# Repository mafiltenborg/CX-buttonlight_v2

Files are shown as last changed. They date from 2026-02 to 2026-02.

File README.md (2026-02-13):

# CX-buttonlight_v2

Better version of the LED lightsource for buttons in your [Citroën CX](https://en.wikipedia.org/wiki/Citro%C3%ABn_CX).

Building on the learnings from [its predecessor](https://github.com/mafiltenborg/CX_buttonlight), the improved version of this little lightsource adds drop-in placement without the need for neither wiring nor the plastic housing from the existing Citroën part. This enables more light or less powerdraw as required by the user. Also, the light module becomes a whole lot easier to manufacture and put in its final position. This version, however, breaks all the originality because it is a component replacement, not a consumables replacement.

Because this device does not use the OE bulb holder (made out of yellow plastic) it allows for the use of any colour LED you fancy. The green light in the ashtray and the green light near the ignition key and the green light emanating from the dashboard computer can now be accompanied by green light from the buttons, making a unison expression. Some might want that...

Update: This device has now been superseded with  one that uses a different LED driving principle (constant current) and even lower power consumption. Go to [CX buttonlight v3](https://github.com/mafiltenborg/cx_buttonlight_v3) to learn more.

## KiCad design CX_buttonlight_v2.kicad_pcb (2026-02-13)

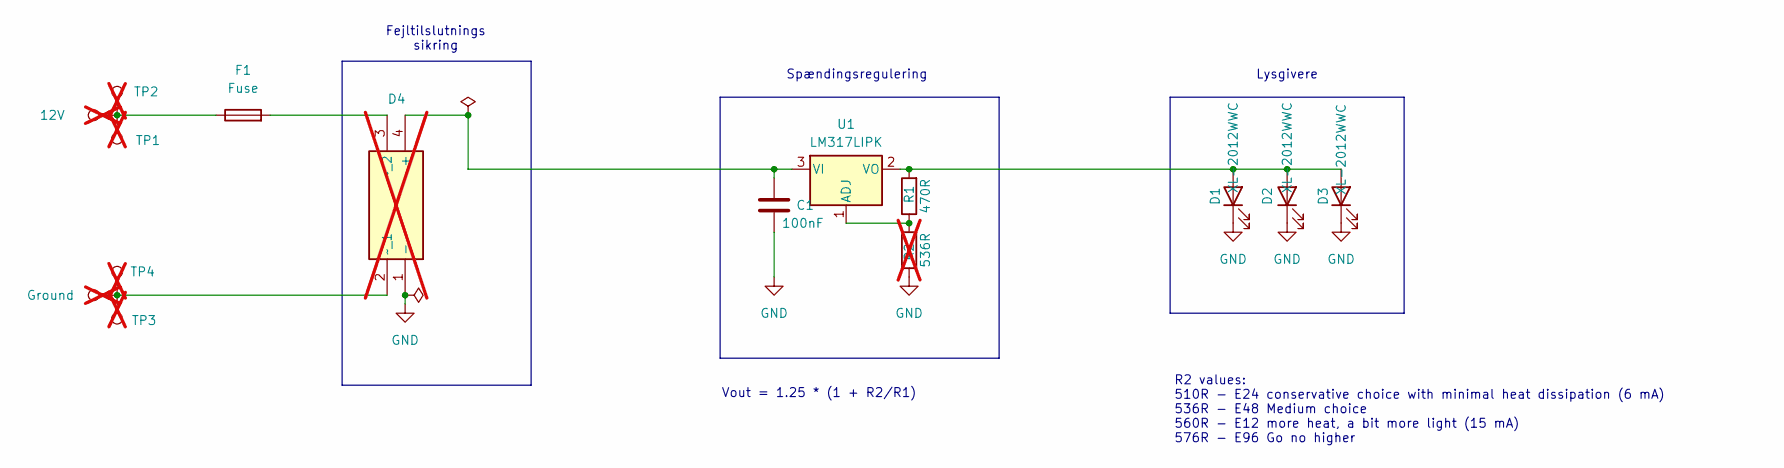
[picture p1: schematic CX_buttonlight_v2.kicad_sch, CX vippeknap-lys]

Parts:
C1: 100nF; C_0805_2012Metric_Pad1.18x1.45mm_HandSolder; LCSC Part # C49678
D1, D2, D3: XL-2012WWC; LED_0805_2012Metric_Pad1.15x1.40mm_HandSolder; LCSC Part # C965820
D4: BAS4002ARPPE6327HTSA1; Manufacturer_Part_Number BAS4002ARPPE6327HTSA1; Mouser Part Number 726-BAS4002ARPPE6; not fitted
F1: Fuse; Fuse_0805_2012Metric_Pad1.15x1.40mm_HandSolder
Ground1: Ground; TestPoint_THTPad_D1.5mm_Drill0.7mm; not fitted
R1: 470R; R_0805_2012Metric_Pad1.20x1.40mm_HandSolder; LCSC Part # C114564
R2: 536R; R_0805_2012Metric_Pad1.20x1.40mm_HandSolder; not fitted
Supply1: 12V; TestPoint_THTPad_D1.5mm_Drill0.7mm; not fitted
TP1, TP2, TP3, TP4: TestPoint; TestPoint_THTPad_D1.5mm_Drill0.7mm; not fitted
U1: LM317LIPK; SOT-89-3; LCSC Part # C112537

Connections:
GND: C1.2, D1.1 (K), D2.1 (K), D3.1 (K), D4.1 (-), R2.1
unnamed: D1.2 (A), D2.2 (A), D3.2 (A), R1.2, U1.2 (VO)
unnamed: C1.1, D4.4 (+), U1.3 (VI)
unnamed: D4.2 (~_1), Ground1.1, TP3.1, TP4.1
unnamed: D4.3 (~_2), F1.2
unnamed: F1.1, Supply1.1, TP1.1, TP2.1
unnamed: R1.1, R2.2, U1.1 (ADJ)

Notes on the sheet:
Fejltilslutnings sikring
R2 values: 510R - E24 conservative choice with minimal heat dissipation (6 mA) 536R - E48 Medium choice 560R - E12 more heat, a bit more light (15 mA) 576R - E96 Go no higher
Vout = 1.25 * (1 + R2/R1)
Lysgivere
Spændingsregulering

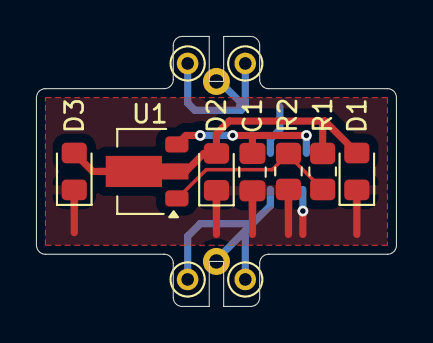
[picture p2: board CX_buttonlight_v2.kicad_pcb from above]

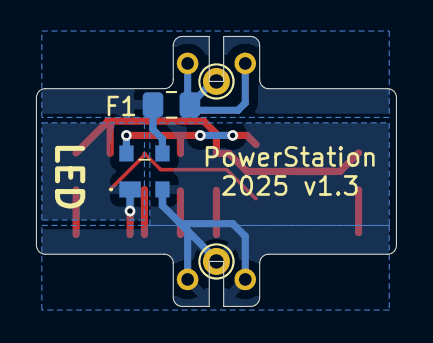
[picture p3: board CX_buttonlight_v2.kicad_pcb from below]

Board: 2 copper layers, 20.0 x 15.0 mm, 15 parts (4 on the bottom side), 7 nets.
